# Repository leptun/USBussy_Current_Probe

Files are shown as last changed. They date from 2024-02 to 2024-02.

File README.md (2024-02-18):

# USBussy_Current_Probe

This project is a simple USB current probe for my PC. It can function in two modes which are selctable via jumpers:
- As two ganged USB downstream facing ports (1x typeA, 1x typeC) that are connected to my PC's internal USB 2.0 headers.
- As a single typeA downstream facing port with a typeC upstream facing port.

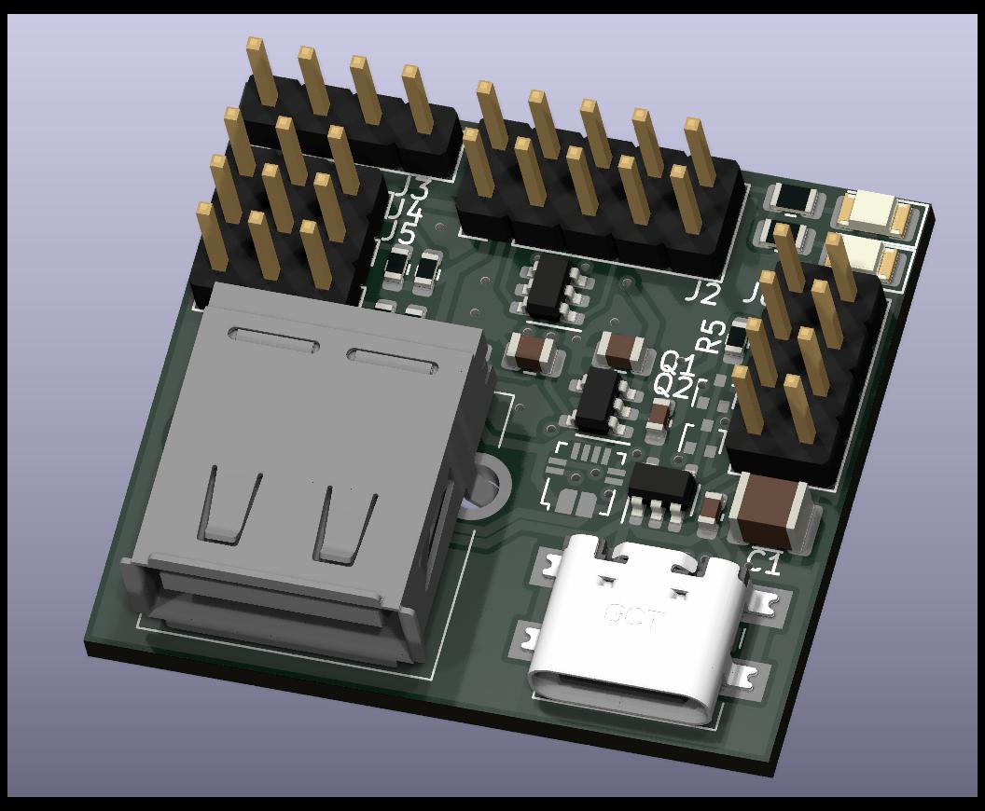
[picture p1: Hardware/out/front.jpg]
PCB_Front

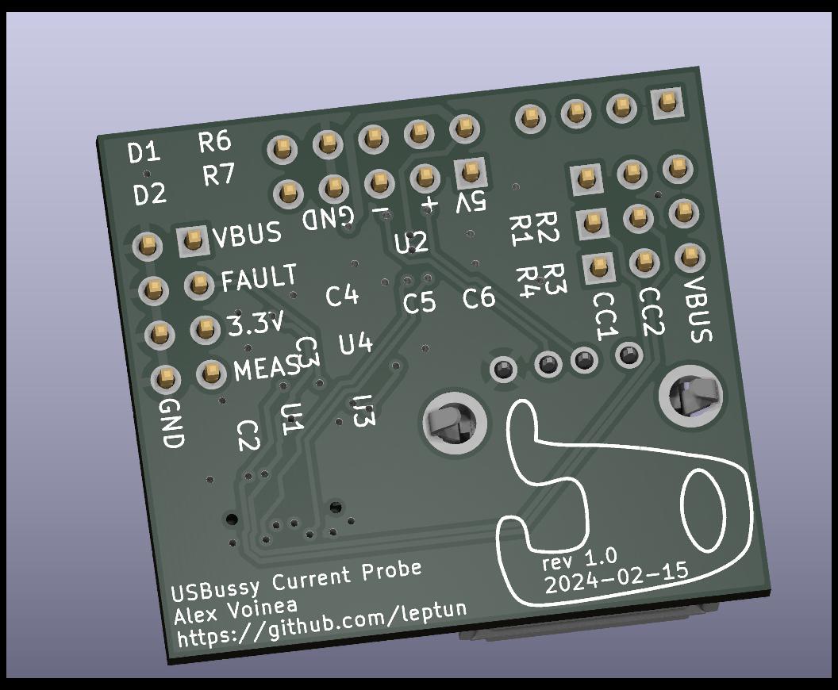
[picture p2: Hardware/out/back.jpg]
PCB_Back


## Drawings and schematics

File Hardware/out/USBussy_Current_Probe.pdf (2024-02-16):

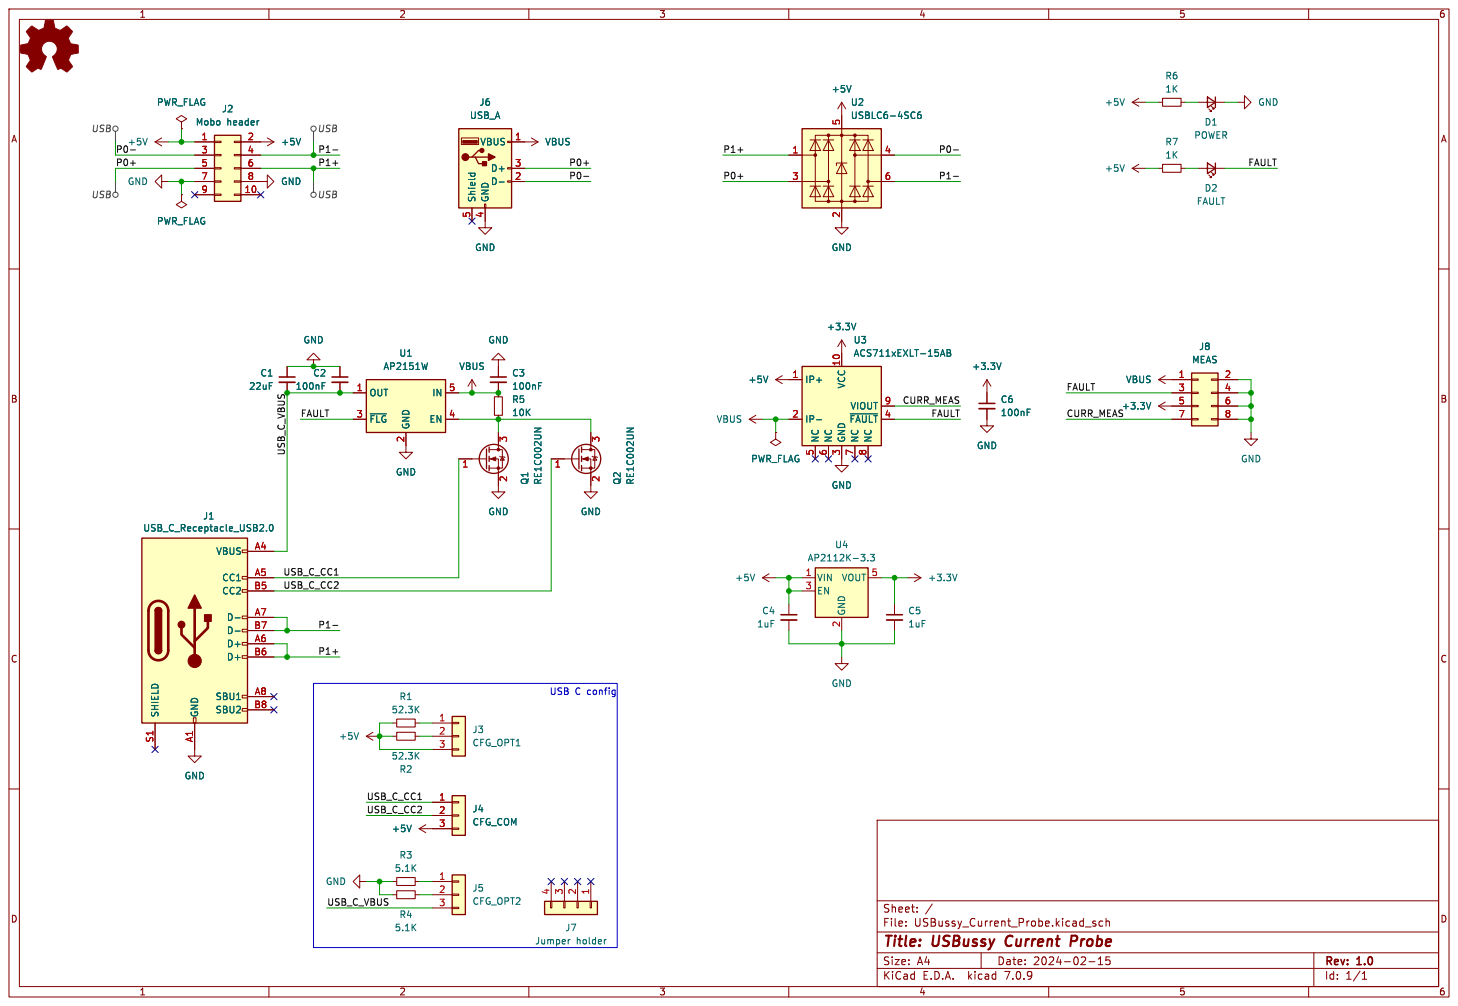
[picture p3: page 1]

File: USBussy_Current_Probe.kicad_sch Sheet: /
Id: 1/1 Title: USBussy Current Probe

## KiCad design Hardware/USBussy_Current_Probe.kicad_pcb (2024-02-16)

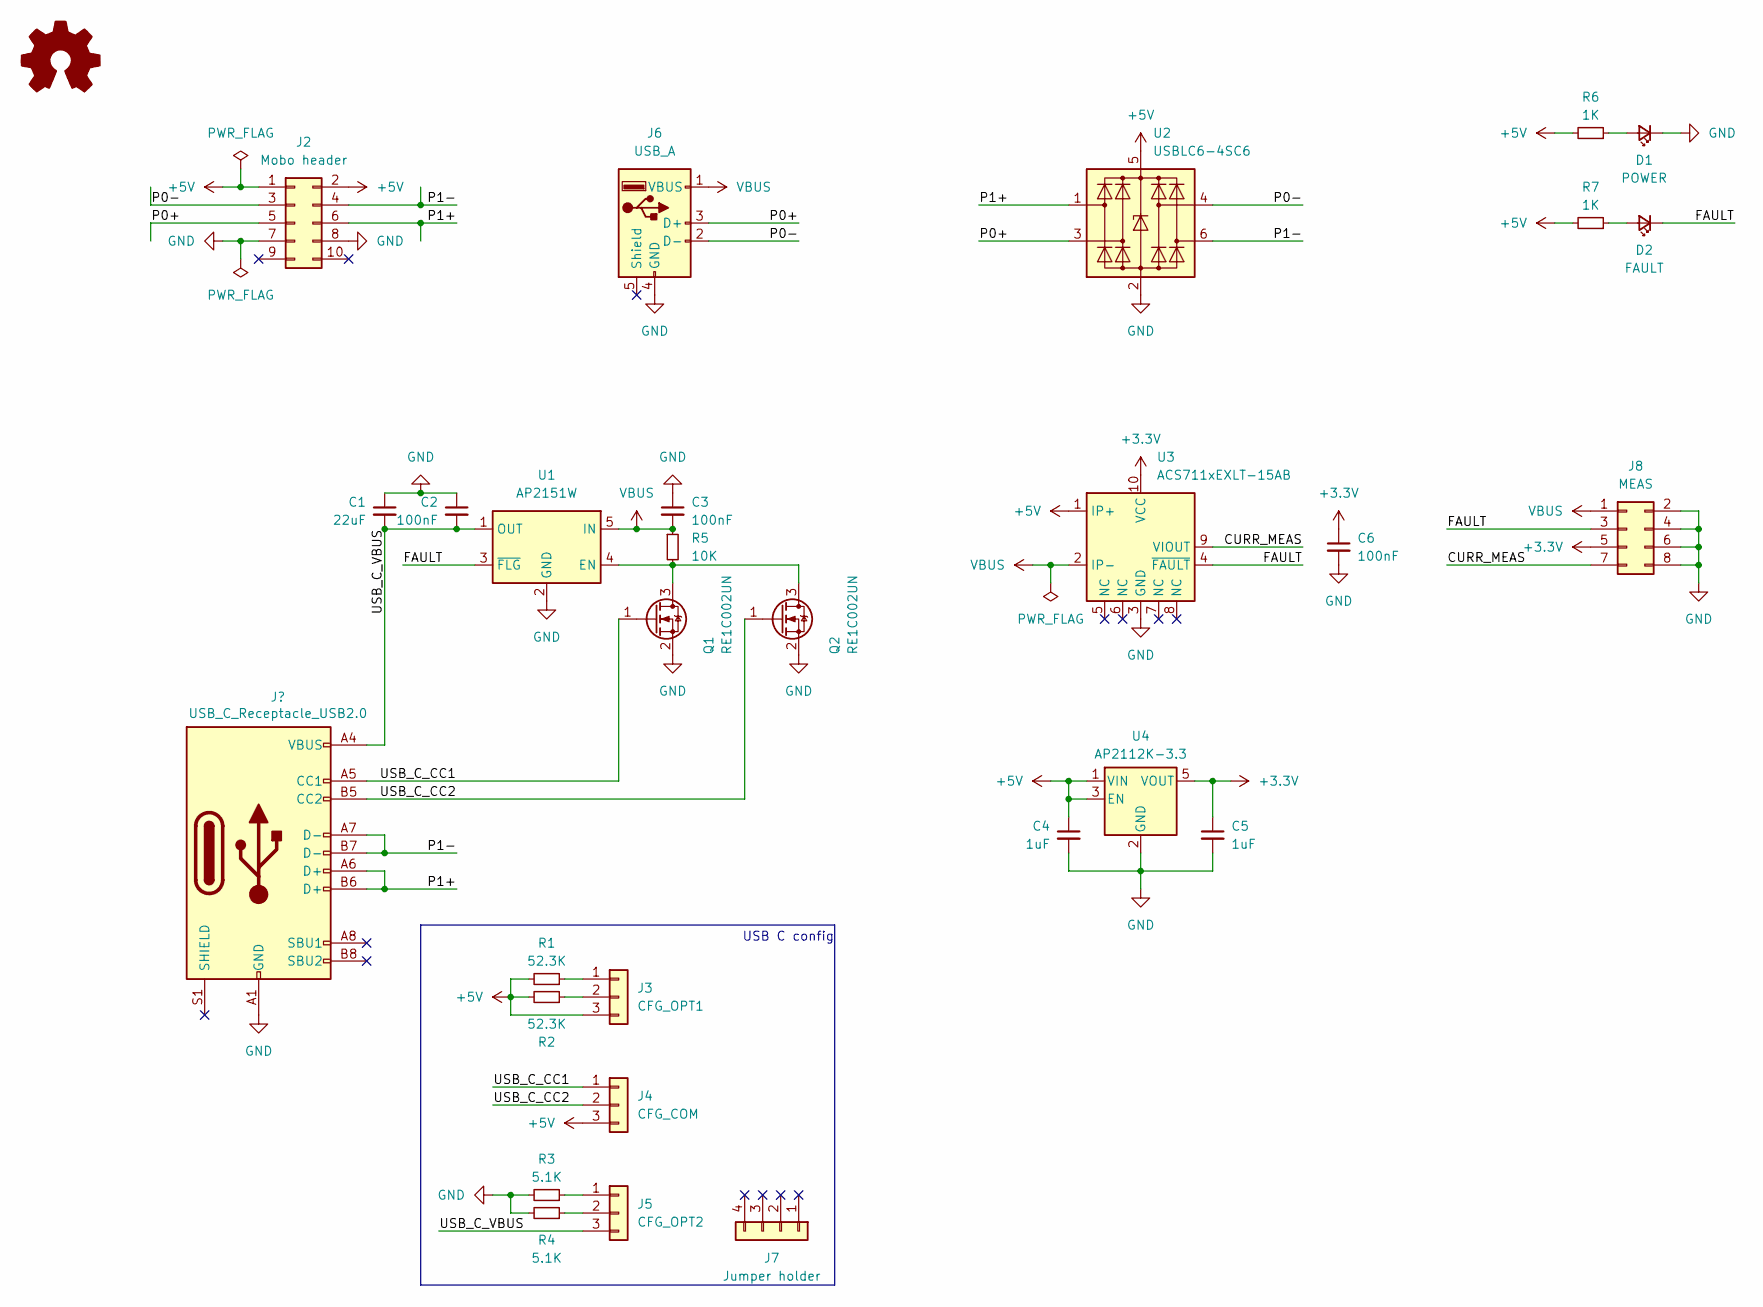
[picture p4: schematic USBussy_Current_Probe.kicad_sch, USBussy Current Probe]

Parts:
C1: 22uF; C_1210_3225Metric
C2, C3, C6: 100nF; C_0603_1608Metric
C4, C5: 1uF; C_0805_2012Metric
D1: POWER; LED_1206_3216Metric
D2: FAULT; LED_1206_3216Metric
J1: USB_C_Receptacle_USB2.0; USB4110-GF-A
J2: Mobo header; PinHeader_2x05_P2.54mm_Vertical
J3: CFG_OPT1; PinHeader_1x03_P2.54mm_Vertical
J4: CFG_COM; PinHeader_1x03_P2.54mm_Vertical
J5: CFG_OPT2; PinHeader_1x03_P2.54mm_Vertical
J6: USB_A; 67643-0910
J7: Jumper holder; PinHeader_1x04_P2.54mm_Vertical
J8: MEAS; PinHeader_2x04_P2.54mm_Vertical
Q1, Q2: RE1C002UN; SOT-416
R1, R2: 52.3K; R_0603_1608Metric
R3, R4: 5.1K; R_0603_1608Metric
R5: 10K; R_0603_1608Metric
R6, R7: 1K; R_0805_2012Metric
SYM1: AMOGUS
U1: AP2151W; SOT-23-5
U2: USBLC6-4SC6; SOT-23-6
U3: ACS711xEXLT-15AB; Allegro_QFN-12-10-1EP_3x3mm_P0.5mm
U4: AP2112K-3.3; SOT-23-5

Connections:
+3.3V: C5.1, C6.1, J8.5, U3.10 (VCC), U4.5 (VOUT)
+5V: C4.1, J2.1, J2.2, J3.3, J4.3, R1.2, R2.2, R6.2, R7.2, U2.5 (VBUS), U3.1 (IP+), U4.1 (VIN), U4.3 (EN)
/CURR_MEAS: J8.7, U3.9 (VIOUT)
/FAULT: D2.1 (K), J8.3, U1.3 (~FLG), U3.4 (~FAULT)
/P0+: J2.5, J6.3 (D+), U2.3 (I/O2)
/P0-: J2.3, J6.2 (D-), U2.4 (I/O3)
/P1+: J1.A6 (D+), J1.B6 (D+), J2.6, U2.1 (I/O1)
/P1-: J1.A7 (D-), J1.B7 (D-), J2.4, U2.6 (I/O4)
/USB_C_CC1: J1.A5 (CC1), J4.1, Q1.1 (G)
/USB_C_CC2: J1.B5 (CC2), J4.2, Q2.1 (G)
/USB_C_VBUS: C1.2, C2.2, J1.A4 (VBUS), J1.A9 (VBUS), J1.B4 (VBUS), J1.B9 (VBUS), J5.3, U1.1 (OUT)
GND: C1.1, C2.1, C3.1, C4.2, C5.2, C6.2, D1.1 (K), J1.A1 (GND), J1.A12 (GND), J1.B1 (GND), J1.B12 (GND), J2.7, J2.8, J6.4 (GND), J8.2, J8.4, J8.6, J8.8, Q1.2 (S), Q2.2 (S), R3.2, R4.2, U1.2 (GND), U2.2 (GND), U3.3 (GND), U4.2 (GND)
unnamed: D1.2 (A), R6.1
unnamed: D2.2 (A), R7.1
unnamed: J3.1, R1.1
unnamed: J3.2, R2.1
unnamed: J5.1, R3.1
unnamed: J5.2, R4.1
unnamed: Q1.3 (D), Q2.3 (D), R5.2, U1.4 (EN)
VBUS: C3.2, J6.1 (VBUS), J8.1, R5.1, U1.5 (IN), U3.2 (IP-)

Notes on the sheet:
USB C config

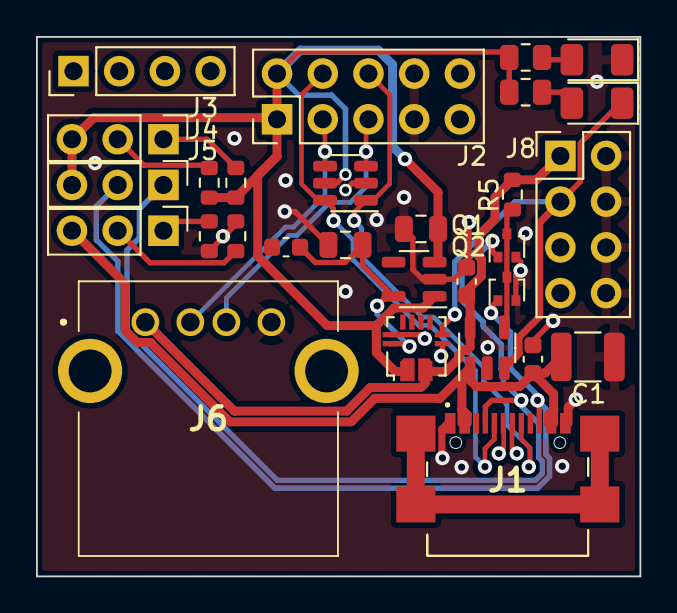
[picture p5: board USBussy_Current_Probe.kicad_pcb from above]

Board: 4 copper layers, 33.5 x 30.0 mm, 30 parts (1 on the bottom side), 20 nets.

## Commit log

2024-02-15 Add texts on board and export
    [USBussy_Current_Probe-B_Cu.gbl, USBussy_Current_Probe-B_Mask.gbs, USBussy_Current_Probe-B_Paste.gbp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]
2024-02-16 Add pinout on silkscreen
    [USBussy_Current_Probe-B_Cu.gbl, USBussy_Current_Probe-B_Mask.gbs, USBussy_Current_Probe-B_Paste.gbp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]
